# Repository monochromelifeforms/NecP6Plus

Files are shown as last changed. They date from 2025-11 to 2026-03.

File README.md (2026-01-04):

# NEC PinWriter P6+

We had this printer growing up. In recent years, I have developed an interest for retro computing.
I found two of these printers cheap on the local equivalent of Craig's List (Kleinanzeigen).

Check the [3D Print Files](3d/README.md) directory for a replacement paper support, which seems to be prone to breaking.

## Next Steps
* Extract fonts from ROMs.
** This is proving to be much harder than I had hoped.
* Build ESP32 module with a web server to print labels.

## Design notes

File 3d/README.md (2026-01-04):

# 3D Print Files

When I bought my 3D printers second hand, 30 years after they had been produced, only one came with the tilt-up paper support,
and on that one of the hinges had broken off.

I modelled a paper support in Fusion 360. It is not an identical copy of the original. Fonts and marks had been embossed on the
original model, and they are now recessed in the model, so that it can be printed with (almost) no supports. The font is bigger
to give the 3D printer a reasonable chance to render them legibly. Chamfers are chosen such that they are printable. In the
case of the bottom edge this means a steeper chamfer than the original model.

The sliders are bespoke to the model, and are not interchangable with the original ones. Only the right hand slider was modelled.
Mirror it in your slicer to obtain the left slider.

When I first printed the model, I did not have one with a bed which was large enough. The model was split, and is joined together
with jigsaw-like features. To give the model stability, cut three 3mm steel rods to a length of about 29cm. The exact length does
not matter; They should just not be too long. The rods are inserted in the three holes on the side after the two pieces are joined
together.

When I finally did get a printer which had a large enough print bed (Anycubic Kobra 3 Max), it was not nearly as good as my
Prusa MK3 in resolving the lettering. A bold font alternative was added for this.

## Slicer Settings

The paper support is printed face-down, the sliders on its "side."

In PrusaSlicer as well as AnycubicSlicerNext, I've used the 0.2mm "quality" preset.

Supports were only painted on the little
nubs that make up the hinge mechanism. For this part, normal supports are prefereable over tree supports. They come off very easily.

Remove any brim that the slicer adds. It's not needed.

When I printed it on my Anycubic, I throttled the speed down to Prusa speeds, to give the printer a chance to lay down the text
in the best way possible.

## Filament Choice

I used "bone white" PLA for the support, which matched the yellowed color of the PinWriters pretty well. I do not intend to
retrobright them. If you do, you'll need a lighter color filament.

For the sliders I used some dar gray PLA I had lying around.

I went with PLA since the parts are not exposed to any significant heat. They have not warped in the years that I've used them.

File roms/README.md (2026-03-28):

# ROMs

There are two 64kB ROMs, split into odd (183) and even (182), for a total of 128k.

The ROMs themselves are not in this repo. I figure if you're here, you have the printer yourself and can dump the ROMs yourself.

## Processing

Since there are two ROMs, and I did not have a ROM merging tool at hand, I quickly wrote one myself (`merge.cpp`).

There are two 64kB ROMs, split into odd (183) and even (182) bytes. This was experimentally determined by
running the Linux command 'strings' over each ROM, and combined, trying both orders.

The `rom2img.py` python script exports the ROM into a PNG image file, interpreting each bit as either black or white, depending on its value, grouped in bytes of three (for the 24 pins).
I was hoping that I copuld "see" where the fonts may be located, but without luck so far.

The next step is to disassemble the ROM. The printer runs a V50 processor, which is an embedded x86-compatible processor.
Assuming the ROM is located at 0xE000 (so that it ends at 0xFFFF), we can start with the reset vector at 0xFFF0.
There is indeed a `jmp` instruction there. I have not proceeded beyond that point.

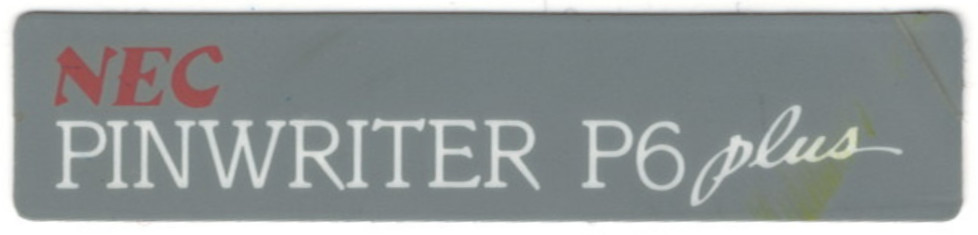
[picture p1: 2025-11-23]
images/decal_scan.jpg

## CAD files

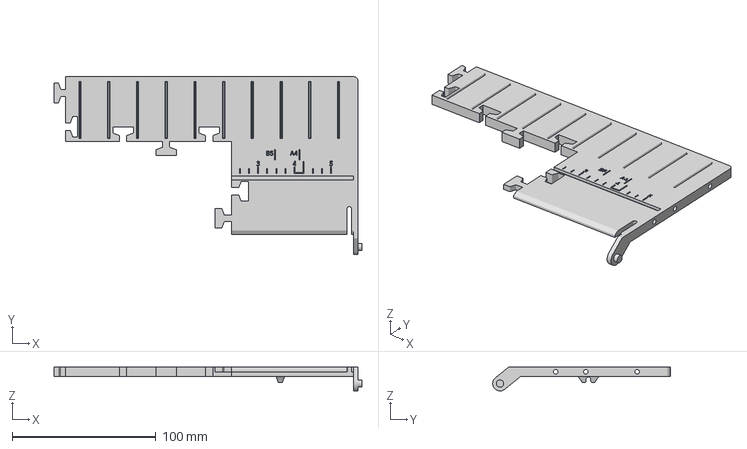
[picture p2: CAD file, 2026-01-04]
3d/paper_support_split_right.3mf
214.4 x 123.7 x 16.7 mm

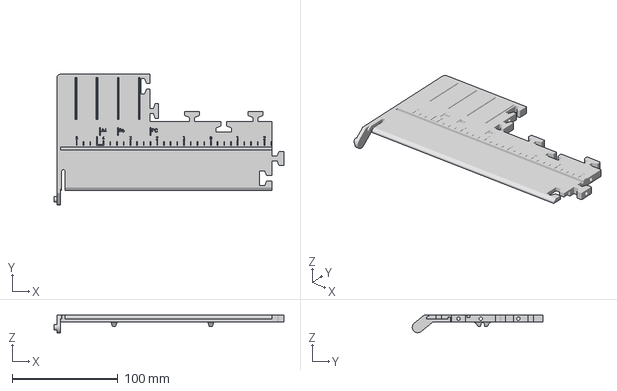
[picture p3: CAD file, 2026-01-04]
3d/paper_support_split_left.3mf
217.9 x 123.7 x 16.7 mm

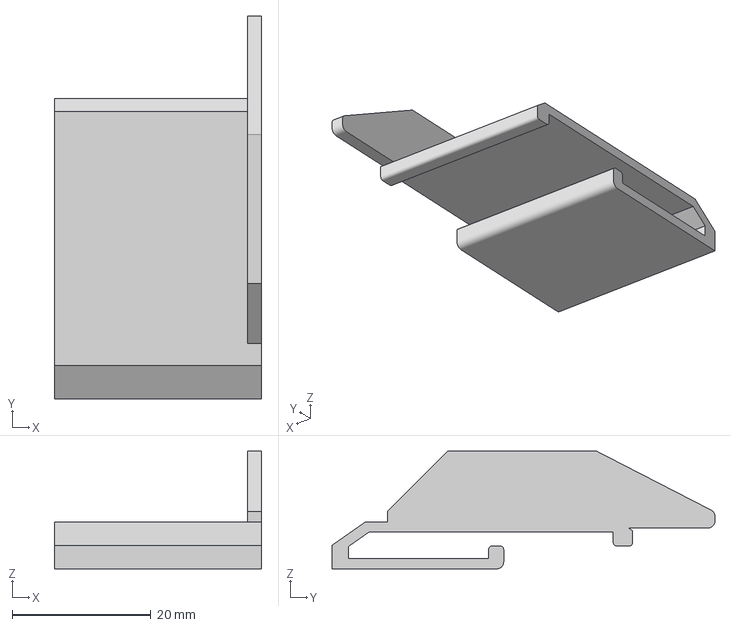
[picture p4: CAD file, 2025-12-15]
3d/slider_right.3mf
29.9 x 55.3 x 17.0 mm

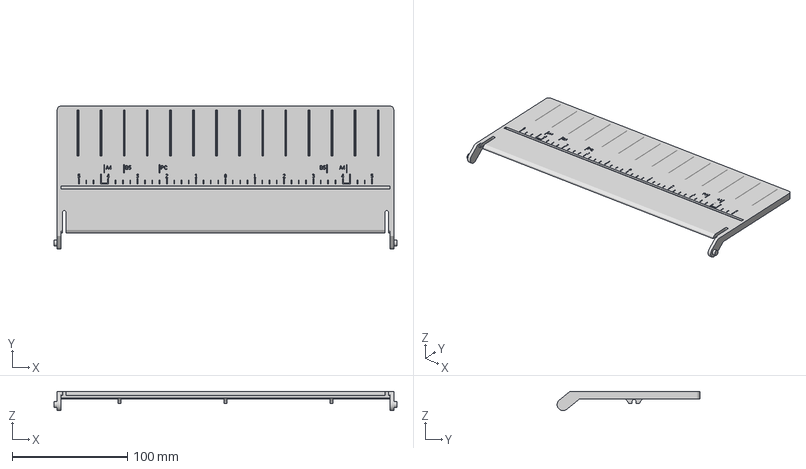
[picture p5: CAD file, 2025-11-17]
3d/paper_support.3mf
297.1 x 123.7 x 16.6 mm

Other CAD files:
3d/paper_support_bold_font.3mf

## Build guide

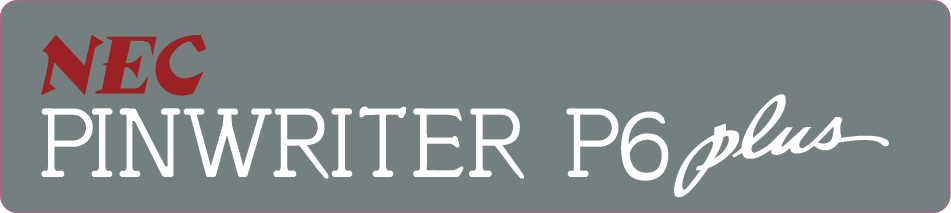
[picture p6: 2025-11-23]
images/decal_reconstructed.png

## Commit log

2025-11-17 [3d] Added 3mf of paper support.
    [paper_support.3mf]
2025-11-17 [3d] Added a bit more information about printing the paper support.
2025-11-22 [3d] Renamed directory, since it will at some point contain things other than the paper support.
    [paper_support.3mf]
2025-11-23 [images] Added label I had peeled off the printer.
2025-11-23 [label] Added reconstructed label, as well as a sheet of printable labels.
2025-11-23 [src] Started prototyping how to write data to the printer.
2025-11-23 [print_label] Actually use the class for changing the type face.
2025-11-25 [src] Reengineered how control codes are sent to the printer.
2025-11-25 [print_label] Fixed a few control codes.
2025-12-15 [3d] Added slider and a split version of the paper support.
    [paper_support_split_left.3mf, paper_support_split_right.3mf, slider_right.3mf]
2026-01-04 [3d] Updated split paper support model; added wide font variant of paper support.
    [paper_support_split_left.3mf, paper_support_split_right.3mf, paper_support_wide_font.3mf]
2026-01-04 [doc] Updated documentation on the 3D models.
    [paper_support_bold_font.3mf]
